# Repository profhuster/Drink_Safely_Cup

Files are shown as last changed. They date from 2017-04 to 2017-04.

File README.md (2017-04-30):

# The Drink Safely Cup
## Designed by profhuster @ gmail.com
## April 2017
This is a dribble cup designed in response to the Make Magazine _worst 
cup_ challenge.

If you hold the handle with your right hand 
and drink out of the cup, it will dribble until empty. If you use 
Your left hand or face the cup in another direction (not looking at 
the "Drink Safely" label) you can drink out of it with out dribbling. 

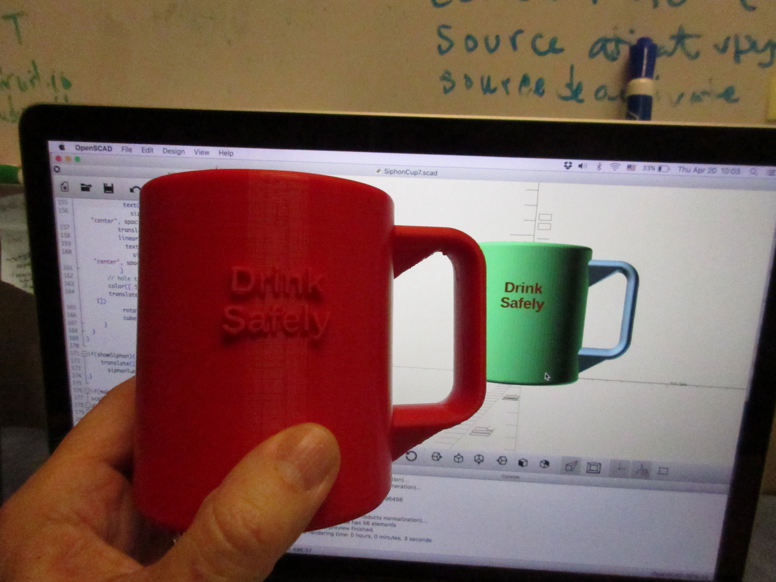
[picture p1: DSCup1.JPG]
Cup with OpenScad in background The Drink Safely Cup

### A Print of the cup with OpenScad image in background.
---

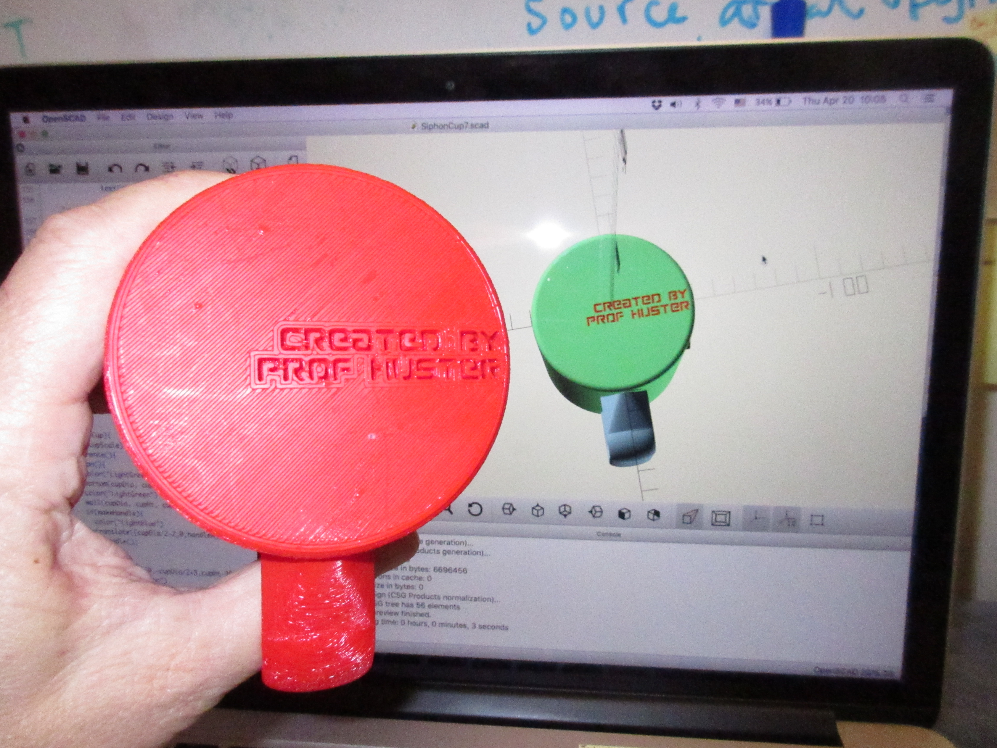
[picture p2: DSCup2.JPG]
Bottom of cup The text on the bottom dribbles

### When dribbling, the fluid leaks through this text.
---

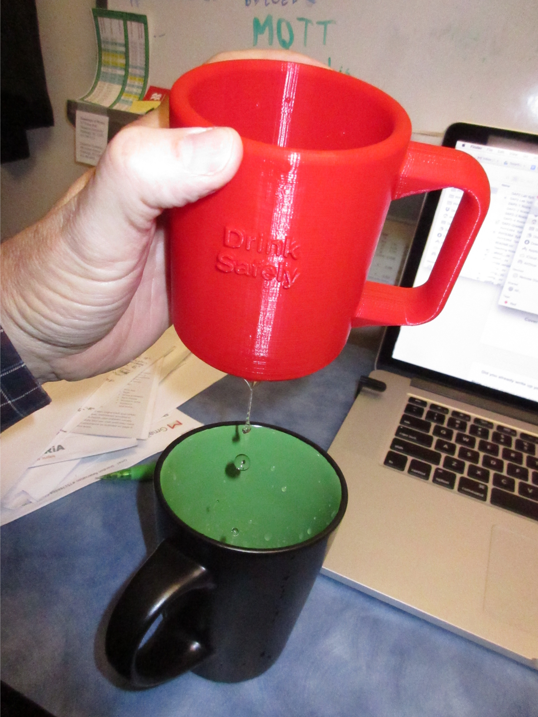
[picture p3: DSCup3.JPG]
Cup with OpenScad in background The cup in action

### The cup completely empties once it starts.
(Sorry I can't get the image rotated correctly.)
---

## The Physics of the Cup
There is a siphon hidden inside the wall of the cup. The inlet to the 
siphon is at the bottom inside the cup. It is very hard to see, even 
if you are looking for it. The vertical siphon tubes run up to the lip 
behind the label "Drink Safely." Once the fluid level reaches the top 
of the siphon tube, water fills the tube starting a siphon. Once the 
siphon starts, it won't stop until the entire cup is drained. The physics 
is like a traditional toilet bowl; the bowl fills until the siphon is 
full, then the bowl drains until air is sucked into the siphon ending 
the process.

The drain is concealed in the indented text on the bottom of the cup, 
so you can't tell that there is a connection to the siphon tube or 
anything fishy.
Some of the letters near the edge are connect to the siphon drain, so 
fluid dribbles from the letters themselves.

I like the design. The insidious nature of the cup is very well 
concealed. 

I built the cup using an OpenSCAD parameter of $fn=96 to make the 
curves smooth.

There are other options in the OpenSCAD code. I try to put all of the 
parameters at the top of the file, so they are easy to change. 

__Warning__: It is a bad idea to send this through a dishwasher. The 
drying cycle may get hot enough to deform the cup. (I experimented 
and found this out.)

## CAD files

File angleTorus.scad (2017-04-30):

/*
 * angleTorus
 * Draw a segment of a torus
 * ProfHuster
 * 2017-04-10
 *
 */
module angleTorus(radX, radZ, od, angle){
    // make a full torus and intersect it with a pie slice
    intersection(){
        // Make a torus of an ellipse (Use scale to make an ellipse)
        rotate_extrude(convexity=10)
            translate([od/2-radX, 0])
            scale([radX/radX, radZ/radX])
              circle(radX);
        // use list conprehension to make an arc
        dArc = 3; // three degree steps
        arcList = [for(th = [0:dArc:angle]) [od*cos(th),od*sin(th)]];
        points = concat([[0,0]], arcList);
        translate([0,0,-radZ])
          linear_extrude(height=2*radZ)
          polygon(points=points);
    }
}

if(false){
    $fn = 48;
    radX = 3;
    radZ = 6;
    OD = 40;
    angleTorus(radX, radZ, OD, 45);
}
// EOF

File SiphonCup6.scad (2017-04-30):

/*
 * Siphon Drinking Mug
 * ProfHuster@gmail.com
 * 2017-04-07
 *
 * If you drink out of this left-handed, you are OK.
 * you drink right-handed ... it dribbles
 * v2 - make using different shapes
 * v3 - added handle using path-like tube and minkowski
 * v4 - 04.10 - better handle. No printing support needed
 **** First version printed and working was v4
 * v6 - improved drain on bottom to be less obvious
 */
include <angleTorus.scad>
$fn = 24;

/* Constants Defined
 */
textOn = true;
makeCup = true;
makeHandle = true;
showSiphon = false;
eps=0.1;
cupScale = 1;
cupDia = 80; // diameter of cup
cupHt = 90; // height of cup
//cupHt = 45; // height of cup
cupRnd = 3; // cup wall thickness = 2x3 = 6 mm
cupText1 = "Drink";
cupText2 = "Safely";
attrText1 = "CREATED BY";
attrText2 = "PROF HUSTER";

// The siphon is hidden except for the drain in the front outside of the cup
// and the siphon hole in the inside front bottom of the cup
siphonDia = 3; // diameter of siphon tube
siphonR = siphonDia/2;
tubeSep = 1; // separation between up & down siphon holes
siphonShowY = -10; 
siphonDelta = 1.5;

handleRad = 4;
handleR = 30;
handleW = 20;
handleH = 40;
handleZScale = 3;
handleFn = $fn/2; // resolution for handle

module bottom(od,rnd) {
  rotate([0,0,-90])
  difference(){
    if(true){
    hull()
      rotate_extrude(convexity = 10)
      translate([od/2-rnd, 0, 0])
      circle(r = rnd);
    }
    // make intaglio text that leaks!
    // Here is the text (intaglio is opposite of embossed)
    color([1,.5,1,.9])
    translate([cupDia/2-cupRnd,0,0])
        rotate([180,0,0])
        union(){
        translate([0,+2.5,-.9])
        linear_extrude(height = 4)
          text(attrText1, font="Liberation Sans:style=Bold",
            size = 3, halign="right", valign="center", spacing = 1 );
        translate([0,-2.5,-.9])
        linear_extrude(height = 4)
          text(attrText2, font="Liberation Sans:style=Bold",
            size = 3, halign="right", valign="center", spacing = 1 );
        }
    // hole to connect drain to text
    color([.5,1,1,.9])
    translate([0, 2*cupRnd,-cupRnd-eps+1])
        rotate([0,0,-90])
        cube([12,cupDia/2-cupRnd,4]);
  }
}

if(!makeCup)
    bottom(cupDia, cupRnd);

module wall(od, ht, rnd){
    rotate_extrude(convexity = 10)
    projection()
    hull(){
        translate([od/2-rnd,0,0])
          cylinder(r = rnd);
        translate([od/2-rnd,ht,0])
          cylinder(r = rnd);
    }
}

// Handle modules
module quarterTorus(radX, radZ, od){
    intersection(){
        rotate_extrude(convexity=10)
            translate([od/2-radX, 0])
            scale([radX/radX, radZ/radX])
              circle(radX);
polyhedron(points = [[0,0,-radZ],[0,0,radZ],[od/2,0,radZ],[od/2,0,-radZ],
                     [0,-od/2,-radZ],[0,-od/2,radZ],
                     [od/2,-od/2,radZ],[od/2,-od/2,-radZ]],
           faces=[[0,1,2,3],[7,6,5,4],[0,4,5,1],[2,6,7,3],[1,5,6,2],[0,3,7,4]]);
        }
}

module handle(){
    rotate([90,0,0])
      union(){
        translate([0,-handleR/2+handleRad,0])
          rotate([0,90,0])
          hull(){
            scale([handleZScale,1,1,])
              cylinder(r=handleRad,h=handleW);
            translate([0,-3*handleRad,0])
              cylinder(r=handleRad,1);
          }
        translate([handleW,0,0])
          quarterTorus(handleRad, handleZScale*handleRad, handleR);
          
        translate([handleW+handleR/2-handleRad,handleH,0])
          rotate([90,0,0])
          scale([1,handleZScale,1,])
          cylinder(r=handleRad,h=handleH);
          
        translate([handleW,handleH,0])
          mirror([0,1,0])
          quarterTorus(handleRad, handleZScale*handleRad, handleR);
          
        translate([0,handleH+handleR/2-handleRad,0])
          rotate([0,90,0])
          hull() {
            scale([handleZScale,1,1,])
              cylinder(r=handleRad,h=handleW);
            translate([0,-3*handleRad,0])
              cylinder(r=handleRad,1);
          }
      }
}

module siphonTube(){
  // Siphon tube
  color([1,0,0])
  translate([0,-cupDia/2+(siphonR+siphonDelta),0])
  union(){
    // drain tube
    translate([-siphonR-tubeSep/2,0,-cupRnd-eps+1.5])
      cylinder(h=cupHt-.5*cupRnd-1.5,r=siphonR);
    // upward tube
    translate([+siphonR+tubeSep/2,0,cupRnd])
      cylinder(h=cupHt-2.5*cupRnd,r=siphonR);
    // horizontal connection at top
    translate([-0,0,cupHt-1.5*cupRnd-.1])
      rotate([90,0,0])
      angleTorus(siphonR,siphonR,4*siphonR+tubeSep,180);
    // drain tube into interior of cup
    translate([+siphonR+tubeSep/2,2*cupRnd,cupRnd+siphonR])
      rotate([90,0,0])
      cylinder(h=1.8*cupRnd,r=siphonR);
  }
}

if(showSiphon){
    translate([0,siphonShowY,0])
      siphonTube();
}

if(makeCup){
scale(cupScale)
difference(){
  union(){
    color("LightGreen")
    bottom(cupDia, cupRnd);
    color("LightGreen")
    wall(cupDia, cupHt, cupRnd);
    if(makeHandle){
      color("LightBlue")
      translate([cupDia/2-2,0,handleR])
        handle();
    }
    if(textOn){
        translate([0,-cupDia/2+3,cupHt-30])
          color("Brown")
          rotate([90,0,0])
          linear_extrude(height = 4)
          text(cupText1, font="Liberation Sans:style=Bold",
            size = 7, halign="center", spacing = 1 );
        translate([0,-cupDia/2+3,cupHt-30-10])
          color("Brown")
          rotate([90,0,0])
          linear_extrude(height = 4)
          text(cupText2, font="Liberation Sans:style=Bold",
            size = 7, halign="center", spacing = 1 );
    }
  }
  siphonTube();
}
} // false
// EOF
